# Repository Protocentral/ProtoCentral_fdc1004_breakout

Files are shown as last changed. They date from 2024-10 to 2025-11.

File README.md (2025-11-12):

Protocentral FDC1004 capacitance sensor breakout board
================================
 

### Don't have one? [Buy it here](https://protocentral.com/product/protocentral-fdc1004-capacitance-sensor-breakout-board/)
### Looking for a more integrated solution? [Check out our FDC1004 & ESP32-S3 based Sensything CAP](https://protocentral.com/product/protocentral-sensything-cap-wireless-pulse-sensor-kit-based-on-afe4400-esp32/)

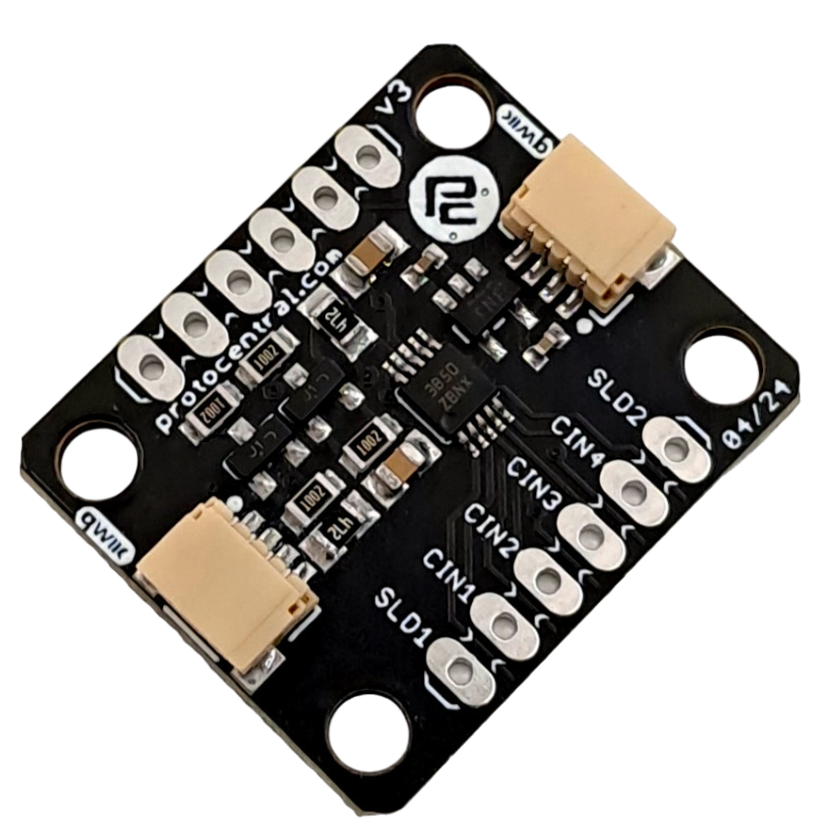
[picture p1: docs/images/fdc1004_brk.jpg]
FDC1004 Breakout
 

The FDC1004 is a single-chip IC for capacitance measurement for application including proximity sensing and liquid level sensing. This is based on the concept of measuring capacitance of an electrode with respect to ground.

This breakout board contains everything to connect it to an Arduino's I2C pins and it can be connected to any other platform with support for I2C two-wire interfaces.

We have made several cool projects with it including proximity sensing and liquid-level sensing from the outside of a tank. Check out our [Hackster page](https://www.hackster.io/team-protocentral/non-contact-capacitive-liquid-level-sensing-using-fdc1004-9333c7) for the detailed project description.

## Hardware Setup
Connection with the Arduino board is as follows:

|FDC1004 pin label| Arduino Connection  |Pin Function      |
 |:-----------------: |:---------------------:|:------------------:|
 | GND                | GND                   |  GND               |
 | SCL                | A5                    |  Serial Clock      |
 | Vcc                | 5V                    |  Power             |
 | SDA                | A4                    |  Serial Data       |

## Software Features

### Multiple I2C Interface Support
The library now supports using different I2C interfaces (Wire, Wire1, etc.) on boards that have multiple I2C ports like ESP32, Arduino Mega, etc.

#### Basic Usage (Default Wire Interface)
```cpp
#include <Wire.h>
#include <Protocentral_FDC1004.h>

FDC1004 sensor(FDC1004_RATE_100HZ);

void setup() {
    Wire.begin();
    sensor.begin();
}
```

#### Custom I2C Interface Usage
```cpp
#include <Wire.h>
#include <Protocentral_FDC1004.h>

// Method 1: TwoWire pointer as first parameter
FDC1004 sensor(&Wire1, FDC1004_RATE_100HZ);

// Method 2: TwoWire pointer as third parameter
// FDC1004 sensor(FDC1004_RATE_100HZ, FDC1004_I2C_ADDRESS, &Wire1);

void setup() {
    Wire1.begin(); // or Wire1.begin(SDA_PIN, SCL_PIN) for ESP32
    sensor.begin();
}
```

## For further details, refer [the documentation on FDC1004 breakout board](https://docs.protocentral.com/getting-started-with-FDC1004/)

## Contributors & Acknowledgments

We appreciate contributions from our community that help improve this library. Special thanks to:

- **@Benicz** - For identifying and reporting the critical CAPDAC hardware configuration bug (v2.0.1).

If you've contributed to this project, please let us know!

License Information
===================

License

This product is open source! Both, our hardware and software are open source and licensed under the following licenses:

Hardware
---------

**All hardware is released under [Creative Commons Share-alike 4.0 International](http://creativecommons.org/licenses/by-sa/4.0/).**


You are free to:

* Share — copy and redistribute the material in any medium or format
* Adapt — remix, transform, and build upon the material for any purpose, even commercially.
The licensor cannot revoke these freedoms as long as you follow the license terms.

Under the following terms:

* Attribution — You must give appropriate credit, provide a link to the license, and indicate if changes were made. You may do so in any reasonable manner, but not in any way that suggests the licensor endorses you or your use.
* ShareAlike — If you remix, transform, or build upon the material, you must distribute your contributions under the same license as the original.

Software
--------

**All software is released under the MIT License(http://opensource.org/licenses/MIT).**

THE SOFTWARE IS PROVIDED "AS IS", WITHOUT WARRANTY OF ANY KIND, EXPRESS OR IMPLIED, INCLUDING BUT NOT LIMITED TO THE WARRANTIES OF MERCHANTABILITY, FITNESS FOR A PARTICULAR PURPOSE AND NONINFRINGEMENT. IN NO EVENT SHALL THE AUTHORS OR COPYRIGHT HOLDERS BE LIABLE FOR ANY CLAIM, DAMAGES OR OTHER LIABILITY, WHETHER IN AN ACTION OF CONTRACT, TORT OR OTHERWISE, ARISING FROM, OUT OF OR IN CONNECTION WITH THE SOFTWARE OR THE USE OR OTHER DEALINGS IN THE SOFTWARE.

Please check [*LICENSE.md*](LICENSE.md) for detailed license descriptions.

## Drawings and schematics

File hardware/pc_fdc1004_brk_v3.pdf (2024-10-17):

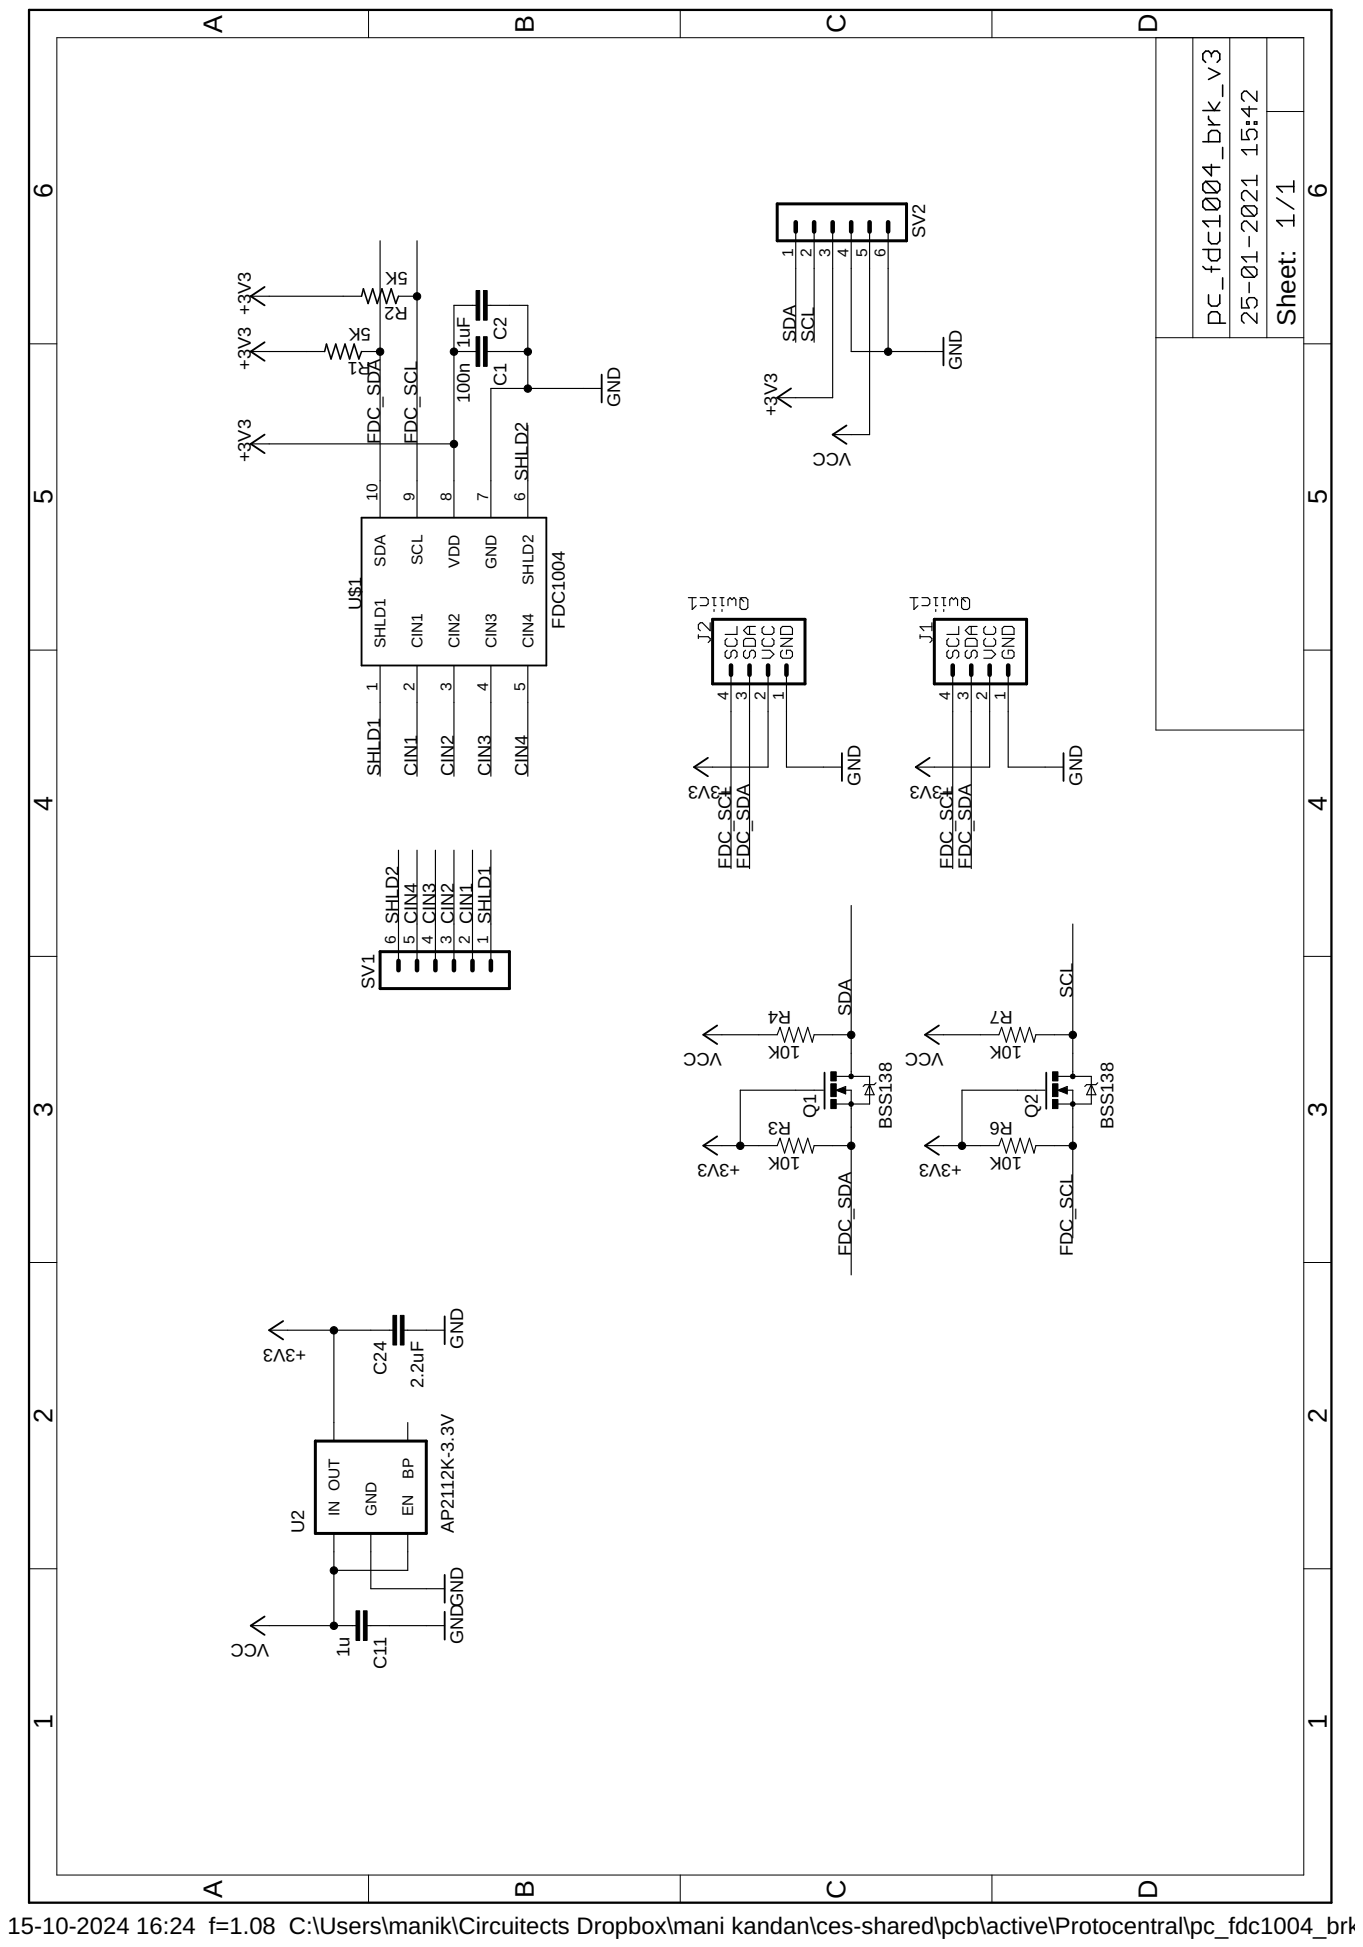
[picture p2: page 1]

15-10-2024 16:24 f=1.08 C:\Users\manik\Circuitects Dropbox\mani kandan\ces-shared\pcb\active\Protocentral\pc_fdc1004_brk_v3\pc_fdc1004_brk_v3.sch (Sheet: 1/1)

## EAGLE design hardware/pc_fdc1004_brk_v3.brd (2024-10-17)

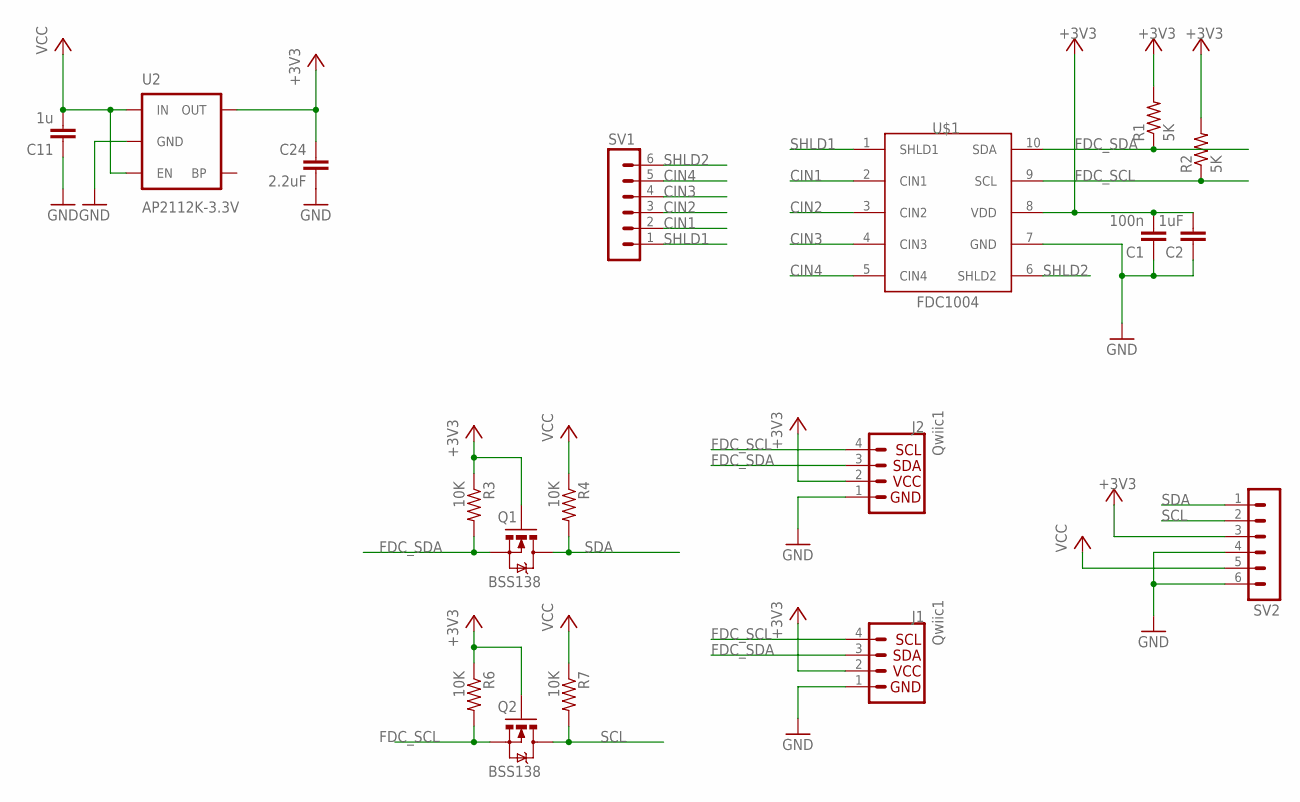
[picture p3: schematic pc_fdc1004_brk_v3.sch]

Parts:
C1: 100n; C0805
C2: 1uF; C0805
C11: 1u; C0402
C24: 2.2uF; C0402
J1, J2: Qwiic1; 1X04_1MM_RA
Q1, Q2: BSS138; SOT23-3
R1, R2: 5K; R0805
R3, R4, R6, R7: 10K; 0603-RES
SV1, SV2: MA06-1
U2: AP2112K-3.3V; SOT23-5
U$1: FDC1004; VSSOP-10

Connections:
+3V3: C1.2, C2.2, C24.1, J1.2, J2.2, Q1.1 (G), Q2.1 (G), R1.2, R2.2, R3.1, R6.1, SV2.3, U2.5 (OUT), U$1.8 (VDD)
CIN1: SV1.2, U$1.2 (CIN1)
CIN2: SV1.3, U$1.3 (CIN2)
CIN3: SV1.4, U$1.4 (CIN3)
CIN4: SV1.5, U$1.5 (CIN4)
FDC_SCL: J1.4, J2.4, Q2.2 (S), R2.1, R6.2, U$1.9 (SCL)
FDC_SDA: J1.3, J2.3, Q1.2 (S), R1.1, R3.2, U$1.10 (SDA)
GND: C1.1, C2.1, C11.1, C24.2, J1.1, J2.1, SV2.4, SV2.6, U2.2 (GND), U$1.7 (GND)
SCL: Q2.3 (D), R7.2, SV2.2
SDA: Q1.3 (D), R4.2, SV2.1
SHLD1: SV1.1, U$1.1 (SHLD1)
SHLD2: SV1.6, U$1.6 (SHLD2)
VCC: C11.2, R4.1, R7.1, SV2.5, U2.1 (IN), U2.3 (EN)

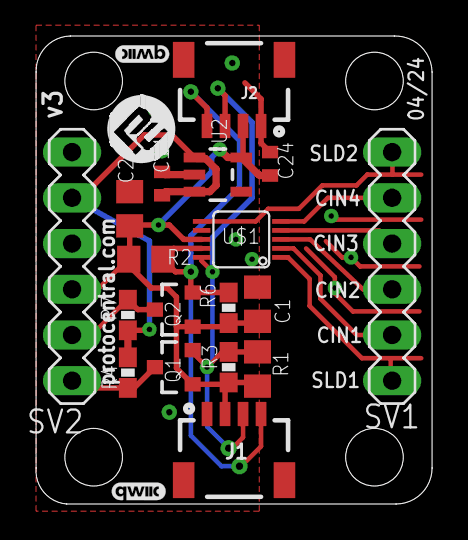
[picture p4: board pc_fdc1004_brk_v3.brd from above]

Board: 2 copper layers, 22.0 x 26.0 mm, 22 parts (1 on the bottom side), 13 nets.

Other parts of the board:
U$2, U$3: QWIIC_3MM
U$4: PCROUNDLOGO
U$5: PCLOG_SMALL_V3

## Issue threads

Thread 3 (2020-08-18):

Unable to read different channel values

nuwanprabhath, 2020-08-18:
Hi,

I'm using the example code you have to get capacitance values of three channels. Even though I pass different channel values to the second parameter of "configureMeasurementSingle", when I'm printing data into the serial console, I can observe that when I touch one electrode, values of all three channels increase rather than one channel. My code is below. I have used the Texas Instrument Sensing Solution software to do the same with the same arrangement and it shows the expected behaviour.

```
#include <Wire.h>
#include <Protocentral_FDC1004.h>

#define UPPER_BOUND  0X4000                 // max readout capacitance
#define LOWER_BOUND  (-1 * UPPER_BOUND)
#define MEASURMENT 0                       // measurment channel

int capdac = 0;
char result[100];

FDC1004 FDC1;
FDC1004 FDC2;
FDC1004 FDC3;

void setup()
{
  Wire.begin();        //i2c begin
  Serial.begin(9600); // serial baud rate
}

void loop()
{
  Serial.print("C2:");
  int channel=1;
  FDC1.configureMeasurementSingle(MEASURMENT, channel, capdac);
  FDC1.triggerSingleMeasurement(MEASURMENT, FDC1004_100HZ);

  //wait for completion
  delay(15);
  uint16_t value[2];
  if (! FDC1.readMeasurement(MEASURMENT, value))
  {
    int16_t msb = (int16_t) value[0];
    int32_t capacitance = ((int32_t)457) * ((int32_t)msb); //in attofarads
    capacitance /= 1000;   //in femtofarads
    capacitance += ((int32_t)3028) * ((int32_t)capdac);

    Serial.print((((float)capacitance/1000)),4);

    if (msb > UPPER_BOUND)               // adjust capdac accordingly
	{
      if (capdac < FDC1004_CAPDAC_MAX)
	  capdac++;
    }
	else if (msb < LOWER_BOUND)
	{
      if (capdac > 0)
	  capdac--;
    }

  }

  Serial.print(":C3:");
  channel=2;

  FDC2.configureMeasurementSingle(MEASURMENT, channel, capdac);
  FDC2.triggerSingleMeasurement(MEASURMENT, FDC1004_100HZ);

  //wait for completion
  delay(15);
  uint16_t value1[2];
  if (! FDC2.readMeasurement(MEASURMENT, value1))
  {
    int16_t msb = (int16_t) value1[0];
    int32_t capacitance = ((int32_t)457) * ((int32_t)msb); //in attofarads
    capacitance /= 1000;   //in femtofarads
    capacitance += ((int32_t)3028) * ((int32_t)capdac);

    Serial.print((((float)capacitance/1000)),4);

    if (msb > UPPER_BOUND)               // adjust capdac accordingly
	{
      if (capdac < FDC1004_CAPDAC_MAX)
	  capdac++;
    }
	else if (msb < LOWER_BOUND)
	{
      if (capdac > 0)
	  capdac--;
    }

  }

  Serial.print(":C4:");
  channel=3;
  FDC3.configureMeasurementSingle(MEASURMENT, channel, capdac);
  FDC3.triggerSingleMeasurement(MEASURMENT, FDC1004_100HZ);

  //wait for completion
  delay(15);
  uint16_t value2[2];
  if (! FDC3.readMeasurement(MEASURMENT, value2))
  {
    int16_t msb = (int16_t) value2[0];
    int32_t capacitance = ((int32_t)457) * ((int32_t)msb); //in attofarads
    capacitance /= 1000;   //in femtofarads
    capacitance += ((int32_t)3028) * ((int32_t)capdac);

    Serial.print((((float)capacitance/1000)),4);

    if (msb > UPPER_BOUND)               // adjust capdac accordingly
	{
      if (capdac < FDC1004_CAPDAC_MAX)
	  capdac++;
    }
	else if (msb < LOWER_BOUND)
	{
      if (capdac > 0)
	  capdac--;
    }

  }
  Serial.println("");
}
```

protocentralashwin, 2025-07-19:
Fixed in release v2.0.0

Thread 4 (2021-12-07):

getRawCapacitance function is undefined

PopovsSergejs, 2021-12-07:
The function which is declared in the header is not implemented in .cpp file. Here is Arduino IDE report

" libraries\ProtoCentral_FDC1004_Capacitive_Sensor_Library\Protocental_FDC1004.cpp.o: In function `FDC1004::getCapacitance(unsigned char)':
C:\Users\sergejsp\Documents\Arduino\libraries\ProtoCentral_FDC1004_Capacitive_Sensor_Library\src/Protocental_FDC1004.cpp:137: undefined reference to `FDC1004::getRawCapacitance(unsigned char, fdc1004_measurement_t*)'
collect2.exe: error: ld returned 1 exit status
exit status 1 "

This function is used in getCapacitance(); function.

protocentralashwin, 2025-07-19:
Added in v2.0.0

Closed 2025-07-19.

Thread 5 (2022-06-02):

Bad trigger request error

pegasus-automation, 2022-06-02:
When connection with ESP32 the bad trigger request message is displayed. What could be the possible reason for that?

Ingo-Muc, 2023-05-23:
@pegasus-automation How did you solve the problem?

Closed 2024-11-29.

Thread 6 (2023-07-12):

Request for clarification about capacitance value determination

Bhindhiya, 2023-07-12:
Hi!

Firstly, thank you for providing this library. It has been very useful to configure and observe FDC1004 behavior.
I humbly request your help to better understand two aspects of your code.

**1. Why is the capacitance value calculation done in the following manner for the board?**

_Following code snippet is from the example code_
`int16_t msb = (int16_t) value[0];`
`int32_t capacitance = ((int32_t)457) * ((int32_t)msb); //in attofarads`
`capacitance /= 1000;   //in femtofarads`
`capacitance += ((int32_t)3028) * ((int32_t)capdac);`

Why is capacitance calculated in this manner? What is the significance of **457** and **3028**?
According to FDC1004 datasheet (page 16), we are required to calculate the 2's complement of the measured value and divide the same by 2^19 to find the capacitance (pF) value. Please correct me if my understanding is incorrect.

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

**2. Why are we not using the measurement LSB value in the calculation?**

Based on FDC1004 datasheet, I understand 24-bit data is available after capacitance measurement from FDC1004. Only bits [0:7] are reserved and the bits [8:15] of LSB register hold valid data. However, we are ignoring this value (bits [8:15] of LSB register) during the calculation. I request you to please clarify the reason for this.

Looking forward to hearing from you as it would be very helpful to me. Thank you!

Closed 2025-07-19.

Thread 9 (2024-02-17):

I seem to only get 0 values from the board using a Teensy 4.0

BryanVision, 2024-02-17:
I couldn't get the library to run, so I used my own code.

```
#include <Wire.h>
#include <IntervalTimer.h>

// FDC1004 I2C address
#define FDC1004_I2C_ADDRESS 0x50

// FDC1004 Configuration Register Addresses
#define FDC_CONF_REG 0x0C
#define MEAS1_CONF_REG 0x08
#define MEAS2_CONF_REG 0x09
#define MEAS3_CONF_REG 0x0A
#define MEAS4_CONF_REG 0x0B

// FDC1004 Measurement Register Addresses for MSB and LSB of each channel
#define MEAS1_MSB 0x00
#define MEAS1_LSB 0x01
#define MEAS2_MSB 0x02
#define MEAS2_LSB 0x03
#define MEAS3_MSB 0x04
#define MEAS3_LSB 0x05
#define MEAS4_MSB 0x06
#define MEAS4_LSB 0x07

// IntervalTimer object
IntervalTimer myTimer;

// Function prototypes
void writeFDCRegister(uint16_t reg, uint16_t value);
void readMeasurement(void);
void readMeasurementTask(void);

void setup() {
  Serial.begin(9600);
  Wire.begin();
  delay(1000); // Wait for Serial monitor to open
  Serial.println("Initializing FDC1004 for all 4 channels...");

  // Set the measurement rate to 100S/s and enable repeat measurements
  writeFDCRegister(FDC_CONF_REG, 0x0C00);

  // Configure all 4 measurement channels for single-ended measurements
  writeFDCRegister(MEAS1_CONF_REG, 0x1C00); // Channel 1
  writeFDCRegister(MEAS2_CONF_REG, 0x1C00); // Channel 2
  writeFDCRegister(MEAS3_CONF_REG, 0x1C00); // Channel 3
  writeFDCRegister(MEAS4_CONF_REG, 0x1C00); // Channel 4

  Serial.println("FDC1004 configured for continuous measurement on all channels.");

  // Set up the hardware timer to call readMeasurementTask every 10ms
  myTimer.begin(readMeasurementTask, 10000); // 10000 microseconds = 10ms
}

void loop() {
  // The readMeasurementTask function is called every 10ms by the hardware timer
  // Nothing needed in the loop
}

void readMeasurementTask() {
  // Read measurement from all channels
  readMeasurement();
}

void readMeasurement() {
  for (int i = 0; i < 4; i++) {
    uint16_t msb = 0, lsb = 0;
    uint8_t msbReg = MEAS1_MSB + (i * 2); // Calculate MSB register for current channel
    uint8_t lsbReg = MEAS1_LSB + (i * 2); // Calculate LSB register for current channel

    // Read MSB
    Wire.beginTransmission(FDC1004_I2C_ADDRESS);
    Wire.write(msbReg >> 8);
    Wire.write(msbReg & 0xFF);
    Wire.endTransmission(false);
    Wire.requestFrom(FDC1004_I2C_ADDRESS, 2);
    if (Wire.available() == 2) {
      msb = Wire.read() << 8;
      msb |= Wire.read();
    }

    // Read LSB
    Wire.beginTransmission(FDC1004_I2C_ADDRESS);
    Wire.write(lsbReg >> 8);
    Wire.write(lsbReg & 0xFF);
    Wire.endTransmission(false);
    Wire.requestFrom(FDC1004_I2C_ADDRESS, 2);
    if (Wire.available() == 2) {
      lsb = Wire.read() << 8;
      lsb |= Wire.read();
    }

    // Print MSB and LSB for the current channel
    Serial.print("Channel ");
    Serial.print(i + 1);
    Serial.print(": MSB=");
    Serial.print(msb, HEX);
    Serial.print(", LSB=");
    Serial.println(lsb, HEX);
  }

  // Print a separator for readability
  Serial.println("------");
}

void writeFDCRegister(uint16_t reg, uint16_t value) {
  Wire.beginTransmission(FDC1004_I2C_ADDRESS);Channel 1: MSB=0, LSB=0
Channel 2: MSB=0, LSB=0
Channel 3: MSB=0, LSB=0
Channel 4: MSB=0, LSB=0
  Wire.write(highByte(reg)); // MSB of register address
  Wire.write(lowByte(reg)); // LSB of register address
  Wire.write(highByte(value)); // MSB of register value
  Wire.write(lowByte(value)); // LSB of register value
  Wire.endTransmission();
}

```

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

I confirmed the arduino teensy 4.0 could see the FDC1004 at its 0x50 address by running:

```

#include <Wire.h>

void setup() {
  Wire.begin();

  Serial.begin(9600);
  while (!Serial); // for Leonardo/Micro/Zero

  Serial.println("\nI2C Scanner");

  byte error, address;
  int nDevices = 0;

  Serial.println("Scanning...");

  for (address = 1; address < 127; address++ ) {
    // The i2c_scanner uses the return value of
    // the Write.endTransmisstion to see if
    // a device did acknowledge to the address.
    Wire.beginTransmission(address);
    error = Wire.endTransmission();

    if (error == 0) {
      Serial.print("I2C device found at address 0x");
      if (address < 16) {
        Serial.print("0");
      }
      Serial.print(address, HEX);
      Serial.println("  !");

      nDevices++;
    }
    else if (error == 4) {
      Serial.print("Unknown error at address 0x");
      if (address < 16) {
        Serial.print("0");
      }
      Serial.println(address, HEX);
    }
  }
  if (nDevices == 0) {
    Serial.println("No I2C devices found\n");
  }
  else {
    Serial.println("done\n");
  }
}

void loop() {
  // nothing to do
}

```

I

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

protocentralashwin, 2025-07-19:
Please check again with v2.0.0

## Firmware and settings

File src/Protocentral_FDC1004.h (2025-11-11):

//////////////////////////////////////////////////////////////////////////////////////////
//
//    Arduino library for the FDC1004 capacitance sensor breakout board
//
//    Author: Ashwin Whitchurch
//    Copyright (c) 2018 ProtoCentral
//
//    Based on original code written by Benjamin Shaya
//
//    This software is licensed under the MIT License(http://opensource.org/licenses/MIT).
//
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
//   For information on how to use, visit https://github.com/protocentral/ProtoCentral_fdc1004_breakout
/////////////////////////////////////////////////////////////////////////////////////////

#ifndef _FDC1004
#define _FDC1004

#include "Arduino.h"
#include "Wire.h"

//Constants and limits for FDC1004
#define FDC1004_100HZ (0x01)
#define FDC1004_200HZ (0x02)
#define FDC1004_400HZ (0x03)
#define FDC1004_IS_RATE(x) (x == FDC1004_100HZ || \
                            x == FDC1004_200HZ || \
                            x == FDC1004_400HZ)

// Sample rate constants for new enum
#define FDC1004_SAMPLE_RATE_100HZ (0x01)
#define FDC1004_SAMPLE_RATE_200HZ (0x02)
#define FDC1004_SAMPLE_RATE_400HZ (0x03)

// I2C Address
#define FDC1004_I2C_ADDRESS (0x50)

// Register addresses
#define FDC1004_REG_MEAS1_MSB (0x00)
#define FDC1004_REG_MEAS1_LSB (0x01)
#define FDC1004_REG_MEAS2_MSB (0x02)
#define FDC1004_REG_MEAS2_LSB (0x03)
#define FDC1004_REG_MEAS3_MSB (0x04)
#define FDC1004_REG_MEAS3_LSB (0x05)
#define FDC1004_REG_MEAS4_MSB (0x06)
#define FDC1004_REG_MEAS4_LSB (0x07)
#define FDC1004_REG_CONF_MEAS1 (0x08)
#define FDC1004_REG_CONF_MEAS2 (0x09)
#define FDC1004_REG_CONF_MEAS3 (0x0A)
#define FDC1004_REG_CONF_MEAS4 (0x0B)
#define FDC1004_REG_FDC_CONF (0x0C)
#define FDC1004_REG_DEVICE_ID (0xFF)

// Configuration bit shifts
#define FDC1004_CONF_MEAS_CHA_SHIFT (13)
#define FDC1004_CONF_MEAS_CHB_SHIFT (10)
#define FDC1004_CONF_MEAS_CAPDAC_SHIFT (5)
#define FDC1004_CONF_MEAS_CHB_DISABLED (0x7)
#define FDC1004_CONF_MEAS_CHB_CAPDAC (0x4)  // CHB mode when CAPDAC is used

#define FDC1004_FDC_CONF_RATE_SHIFT (10)
#define FDC1004_FDC_CONF_REPEAT_SHIFT (8)

// Measurement bounds for CAPDAC adjustment
#define FDC1004_UPPER_BOUND (0x4000)
#define FDC1004_LOWER_BOUND (-0x4000)

// Conversion constants
#define FDC1004_ATTOFARADS_UPPER_WORD (457)
#define FDC1004_FEMTOFARADS_CAPDAC (3028)

#define FDC1004_CAPDAC_MAX (0x1F)
#define FDC1004_CHANNEL_MAX (0x03)
#define FDC1004_MEASUREMENT_MAX (0x03)
#define FDC1004_IS_CHANNEL(x) (x >= 0 && x <= FDC1004_CHANNEL_MAX)

#define FDC1004_MEAS_MAX (0x03)
#define FDC1004_IS_MEAS(x) (x >= 0 && x <= FDC1004_MEAS_MAX)

#define FDC_REGISTER (0x0C)

#define ATTOFARADS_UPPER_WORD (457) //number of attofarads for each 8th most lsb (lsb of the upper 16 bit half-word)
#define FEMTOFARADS_CAPDAC (3028) //number of femtofarads for each lsb of the capdac

// =============================================================================
// Data Types and Enumerations
// =============================================================================

/**
 * @brief Error codes returned by FDC1004 functions
 */
typedef enum {
    FDC1004_SUCCESS = 0,                    ///< Operation completed successfully
    FDC1004_ERROR_INVALID_PARAMETER,       ///< Invalid parameter provided
    FDC1004_ERROR_MEASUREMENT_NOT_READY,   ///< Measurement not completed yet
    FDC1004_ERROR_I2C_COMMUNICATION,       ///< I2C communication error
    FDC1004_ERROR_DEVICE_NOT_FOUND,        ///< Device not responding
    FDC1004_ERROR_CAPDAC_OUT_OF_RANGE      ///< CAPDAC value adjustment needed
} fdc1004_error_t;

/**
 * @brief Sample rate options for measurements
 */
typedef enum {
    FDC1004_RATE_100HZ = FDC1004_SAMPLE_RATE_100HZ,    ///< 100 Hz sample rate
    FDC1004_RATE_200HZ = FDC1004_SAMPLE_RATE_200HZ,    ///< 200 Hz sample rate
    FDC1004_RATE_400HZ = FDC1004_SAMPLE_RATE_400HZ     ///< 400 Hz sample rate
} fdc1004_sample_rate_t;

/**
 * @brief Channel identifiers
 */
typedef enum {
    FDC1004_CHANNEL_0 = 0,
    FDC1004_CHANNEL_1 = 1,
    FDC1004_CHANNEL_2 = 2,
    FDC1004_CHANNEL_3 = 3
} fdc1004_channel_t;

/**
 * @brief Measurement slot identifiers
 */
typedef enum {
    FDC1004_MEASUREMENT_1 = 0,
    FDC1004_MEASUREMENT_2 = 1,
    FDC1004_MEASUREMENT_3 = 2,
    FDC1004_MEASUREMENT_4 = 3
} fdc1004_measurement_t;

/**
 * @brief Raw measurement data structure
 */
typedef struct {
    int16_t value;      ///< Raw capacitance measurement value
    uint8_t capdac;     ///< CAPDAC offset used for this measurement
} fdc1004_raw_measurement_t;

/**
 * @brief Processed capacitance measurement
 */
typedef struct {
    float capacitance_pf;       ///< Capacitance in picofarads
    bool capdac_out_of_range;   ///< True if CAPDAC needs adjustment
    uint8_t capdac_used;        ///< CAPDAC value used for measurement
} fdc1004_capacitance_t;

// =============================================================================
// FDC1004 Class Declaration
// =============================================================================
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

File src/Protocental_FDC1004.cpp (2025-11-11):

//////////////////////////////////////////////////////////////////////////////////////////
//
//    Arduino library for the FDC1004 capacitance sensor breakout board
//
//    Author: Ashwin Whitchurch
//    Copyright (c) 2018 ProtoCentral
//
//    Based on original code written by Benjamin Shaya
//
//    This software is licensed under the MIT License(http://opensource.org/licenses/MIT).
//
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
//   For information on how to use, visit https://github.com/protocentral/ProtoCentral_fdc1004_breakout
/////////////////////////////////////////////////////////////////////////////////////////

#include <Protocentral_FDC1004.h>

// =============================================================================
// Private Constants
// =============================================================================

static const uint8_t MEASUREMENT_CONFIG_REGISTERS[] = {
    FDC1004_REG_CONF_MEAS1, FDC1004_REG_CONF_MEAS2,
    FDC1004_REG_CONF_MEAS3, FDC1004_REG_CONF_MEAS4};

static const uint8_t MEASUREMENT_MSB_REGISTERS[] = {
    FDC1004_REG_MEAS1_MSB, FDC1004_REG_MEAS2_MSB,
    FDC1004_REG_MEAS3_MSB, FDC1004_REG_MEAS4_MSB};

static const uint8_t MEASUREMENT_LSB_REGISTERS[] = {
    FDC1004_REG_MEAS1_LSB, FDC1004_REG_MEAS2_LSB,
    FDC1004_REG_MEAS3_LSB, FDC1004_REG_MEAS4_LSB};

static const uint8_t SAMPLE_DELAYS_MS[] = {11, 11, 6, 3}; // Delays for 100Hz, 200Hz, 400Hz

// =============================================================================
// Constructors and Initialization
// =============================================================================

FDC1004::FDC1004(fdc1004_sample_rate_t rate, uint8_t address, TwoWire* wire)
    : _i2c_address(address), _sample_rate(rate), _device_initialized(false), _wire(wire)
{
    // Initialize CAPDAC values to zero
    for (int i = 0; i < 4; i++)
    {
        _capdac_values[i] = 0;
    }
}

FDC1004::FDC1004(TwoWire* wire, fdc1004_sample_rate_t rate, uint8_t address)
    : _i2c_address(address), _sample_rate(rate), _device_initialized(false), _wire(wire)
{
    // Initialize CAPDAC values to zero
    for (int i = 0; i < 4; i++)
    {
        _capdac_values[i] = 0;
    }
}

FDC1004::FDC1004(uint16_t rate)
    : _i2c_address(FDC1004_I2C_ADDRESS), _device_initialized(false), _wire(&Wire)
{
    // Legacy constructor - convert rate to new enum
    switch (rate)
    {
    case FDC1004_SAMPLE_RATE_100HZ:
        _sample_rate = FDC1004_RATE_100HZ;
        break;
    case FDC1004_SAMPLE_RATE_200HZ:
        _sample_rate = FDC1004_RATE_200HZ;
        break;
    case FDC1004_SAMPLE_RATE_400HZ:
        _sample_rate = FDC1004_RATE_400HZ;
        break;
    default:
        _sample_rate = FDC1004_RATE_100HZ;
        break;
    }

    // Initialize CAPDAC values to zero
    for (int i = 0; i < 4; i++)
    {
        _capdac_values[i] = 0;
    }
}

bool FDC1004::begin()
{
    // Initialize the TwoWire interface
    _wire->begin();
    
    // Check if device is responding
    if (!isConnected())
    {
        return false;
    }

    _device_initialized = true;
    return true;
}

bool FDC1004::isConnected()
{
    uint16_t device_id;
    fdc1004_error_t result = readRegister16(FDC1004_REG_DEVICE_ID, &device_id);
    return (result == FDC1004_SUCCESS);
}

// =============================================================================
// High-Level Measurement Functions
// =============================================================================

fdc1004_capacitance_t FDC1004::getCapacitanceMeasurement(fdc1004_channel_t channel)
{
    fdc1004_capacitance_t result;
    result.capacitance_pf = NAN;
    result.capdac_out_of_range = false;
    result.capdac_used = 0;

    if (!_device_initialized || !isValidChannel(channel))
    {
        return result;
    }

    fdc1004_raw_measurement_t raw_measurement;
    fdc1004_error_t error = getRawCapacitance(channel, &raw_measurement);

    if (error == FDC1004_SUCCESS)
    {
        result.capacitance_pf = convertToPicofarads(raw_measurement.value, raw_measurement.capdac);
        result.capdac_used = raw_measurement.capdac;

        // Check if CAPDAC adjustment is needed
        if (raw_measurement.value > FDC1004_UPPER_BOUND ||
            raw_measurement.value < FDC1004_LOWER_BOUND)
        {
            result.capdac_out_of_range = true;
            autoAdjustCapdac(channel, raw_measurement.value);
        }
    }

    return result;
}

float FDC1004::getCapacitancePicofarads(fdc1004_channel_t channel)
{
    fdc1004_capacitance_t measurement = getCapacitanceMeasurement(channel);
    return measurement.capacitance_pf;
}

int32_t FDC1004::getCapacitance(uint8_t channel)
{
    // Legacy function - returns femtofarads
    if (!isValidChannel(channel))
    {
        return 0x80000000; // Error value
    }

    fdc1004_raw_measurement_t value;
    fdc1004_error_t result = getRawCapacitance((fdc1004_channel_t)channel, &value);
    if (result != FDC1004_SUCCESS)
    {
        return 0x80000000; // Error value
    }

    // Convert to femtofarads (legacy format)
    int32_t capacitance = ((int32_t)FDC1004_ATTOFARADS_UPPER_WORD) * ((int32_t)value.value);
    capacitance /= 1000; // Convert attofarads to femtofarads
    capacitance += ((int32_t)FDC1004_FEMTOFARADS_CAPDAC) * ((int32_t)value.capdac);
    return capacitance;
}

// =============================================================================
// Configuration and Control
// =============================================================================

fdc1004_error_t FDC1004::setSampleRate(fdc1004_sample_rate_t rate)
{
    if (!isValidSampleRate(rate))
    {
        return FDC1004_ERROR_INVALID_PARAMETER;
    }

    _sample_rate = rate;
    return FDC1004_SUCCESS;
}

fdc1004_sample_rate_t FDC1004::getSampleRate() const
{
    return _sample_rate;
}

fdc1004_error_t FDC1004::setCapdac(fdc1004_channel_t channel, uint8_t capdac)
{
    if (!isValidChannel(channel) || !isValidCapdac(capdac))
    {
        return FDC1004_ERROR_INVALID_PARAMETER;
    }

    _capdac_values[channel] = capdac;
    return FDC1004_SUCCESS;
}

uint8_t FDC1004::getCapdac(fdc1004_channel_t channel) const
{
    if (!isValidChannel(channel))
    {
        return 0;
    }
    return _capdac_values[channel];
}

// =============================================================================
// Low-Level Hardware Interface (New Implementation)
// =============================================================================
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

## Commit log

2016-12-17 Added hardware schematics
    [pc_fdc1004_brk.brd, pc_fdc1004_brk.sch]
2016-12-19 updated arduino library
2018-04-18 Updated broken links, images
    [Protocental_FDC1004.cpp, Protocentral_FDC1004.h]
2023-09-30 Remove begin/endTransmission() around Wire.read()
2023-09-30 Add missing return statement
    [Protocental_FDC1004.cpp]
2024-10-17 schematics,images and readme updated
    [pc_fdc1004_brk.brd, pc_fdc1004_brk_v3.brd, pc_fdc1004_brk_v3.sch]
2025-07-17 Code refactoring
    - ✅ Restructured code into logical sections with clear documentation
    - ✅ Implemented robust error handling throughout
    - ✅ Added automatic CAPDAC adjustment algorithm
    - ✅ Improved I2C communication with proper error checking
    - ✅ Created conversion utilities for different units
    - ✅ Added input validation for all parameters
    - ✅ Maintained full backward compatibility
    [Protocental_FDC1004.cpp, Protocentral_FDC1004.h]
2025-07-18 Fix enum declaration issue
    [Protocentral_FDC1004.h]

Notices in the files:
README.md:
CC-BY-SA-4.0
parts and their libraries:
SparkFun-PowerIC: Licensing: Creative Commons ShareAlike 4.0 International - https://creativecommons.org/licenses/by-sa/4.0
